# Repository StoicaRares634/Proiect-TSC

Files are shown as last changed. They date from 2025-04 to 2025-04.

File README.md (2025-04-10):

# Proiect-TSC
Proiect-TSC Stoica Rares-Nicolae 333CA

| Device | CHECK_PRICES |
|---|---|
| ESP32_WROVER_EAGLE-LTSPICE_CC0402 | |
| RCL_CPOL-EUCT3528 | https://a360.co/4iZy6AA |
| CPH3225A | https://www.snapeda.com/parts/CPH3225A/Seiko+Instruments/view-part/?ref=eda |
| BUTTON_CUSYOMV1 | https://industry.panasonic.com/global/en/products/control/switch/light-touch/number/evqpuj02k |
| ADAFRUIT_LEDCHIP-LED0603 | https://www.snapeda.com/parts/KP-1608SURCK/Kingbright/view-part/?ref=search |
| USBLC6-2SC6Y | https://www.snapeda.com/parts/USBLC6-2SC6Y/STMicroelectronics/view-part/?ref=eda |
| ESP32_WROVER_AVX---SD0805S020S1R0 | https://eu.mouser.com/ProductDetail/KYOCERA-AVX/SD0805S020S1R0?qs=jCA%252BPfw4LHbpkAoSnwrdjw%3D%3D |
| MBR0530 | https://www.snapeda.com/parts/MBR0530/Onsemi/view-part/?ref=eda |
| PGB1010603MR | https://www.snapeda.com/parts/PGB1010603MR/Littelfuse/view-part/?ref=eda |
| BD5229G-TR | https://componentsearchengine.com/part-view/BD5229G-TR/ROHM%20Semiconductor |
| XC6220A331MR-G | https://componentsearchengine.com/part-view/XC6220A331MR-G/Torex |
| FH34SRJ-24S-0.5SH_99_ | https://componentsearchengine.com/part-view/XC6220A331MR-G/Torex |
| SAMACSYS_PARTS_USB4110-GF-A | https://componentsearchengine.com/part-view/USB4110-GF-A/GCT%20(GLOBAL%20CONNECTOR%20TECHNOLOGY) |
| 112A-TAAR-R03_ATTEND | https://store.comet.srl.ro/Catalogue/Product/43497/ |
| 744043680IND_4828-WE-TPC_WRE | https://eu.mouser.com/ProductDetail/Wurth-Elektronik/744043680?qs=PGXP4M47uW6VkZq%252BkzjrHA%3D%3D |
| ESP32C6_VARISTORCN1812 | https://www.mouser.co.uk/ProductDetail/EPCOS-TDK/B72520T0350K062?qs=dEfas%2FXlABIszF52uu7vrg%3D%3D |
| ESP32_WROVER_SPARKFUN-DISCRETESEMI_MOSFET_PCH-DMG2305UX-7 | https://componentsearchengine.com/part-view/DMG2305UX-7/Diodes%20Incorporated |
| D8 | https://componentsearchengine.com/part-view/SI1308EDL-T1-GE3/Vishay |
| ESP32_WROVER_EAGLE-LTSPICE_RR0402 | https://componentsearchengine.com/part-view/R0402%201%25%20100%20K%20(RC0402FR-07100KL)/YAGEO |
| BME680 | https://www.snapeda.com/parts/BME680/Bosch/view-part/?welcome=home |
| SJ | https://grabcad.com/library/solder-jumpers-1 |
| W25Q512JVEIQ | https://www.snapeda.com/parts/W25Q512JVEIQ/Winbond+Electronics/view-part/?ref=eda |
| ESP32-C6-WROOM-1-N8 | https://www.snapeda.com/parts/ESP32-C6-WROOM-1-N8/Espressif+Systems/view-part/?ref=eda |
| DS3231SN# | https://www.snapeda.com/parts/DS3231SN%23/Analog+Devices/view-part/?ref=eda |
| MAX17048G+T10 | https://www.snapeda.com/parts/MAX17048G+T10/Analog+Devices/view-part/?ref=eda |

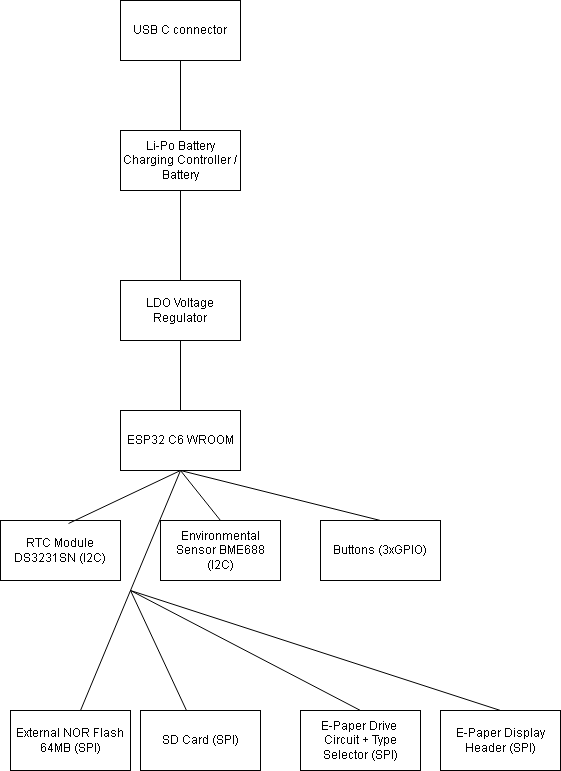
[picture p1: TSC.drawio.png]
diagrama


## Descriere detaliata a functionalitatii hardware

Proiectul utilizeaza microcontroller-ul ESP32-C6 WROOM. Acesta gestioneaza comunicatia cu diverse module prin interfete SPI, I2C si GPIO, avand capacitate extinsa pentru conectivitate wireless si control de periferice.

### Structura de alimentare

- Conector USB-C: asigura alimentarea externa si transferul de date.
- Controler incarcare baterie Li-Po (MCP73831): integreaza functii de incarcare sigura si controlata a bateriei.
- Baterie Li-Po: sursa de energie mobila, folosita pentru autonomie.
- LDO Regulator (XC6206): reduce tensiunea de la baterie la 3.3V stabili, necesari ESP32 si altor componente.

### Module conectate la ESP32-C6 si interfetele lor

#### 1. Senzor ambiental BME688
- Interfata: I2C
- Functii: detecteaza temperatura, presiune, umiditate si compusi volatili (calitate aer).
- Pini ESP32-C6:
  - GPIO4 → SDA
  - GPIO5 → SCL
GPIO4 si GPIO5 sunt GPIO standard cu suport I2C hardware.

#### 2. Modul RTC – DS3231SN
- Interfata: I2C
- Functii: mentine timpul real precis, inclusiv in standby.
- Pini ESP32-C6:
  - Impartiti cu BME688: GPIO4 (SDA) si GPIO5 (SCL)

#### 3. Memorie externa NOR Flash – W25Q512JVEIQ
- Interfata: SPI
- Functii: stocare extensiva de date nevolatile (64MB).
- Pini ESP32-C6:
  - GPIO6 → CLK
  - GPIO7 → MISO
  - GPIO8 → MOSI
  - GPIO9 → CS (Flash)
Aceasta configuratie este conforma cu pinii dedicati SPI al ESP32-C6 pentru performanta maxima.

#### 4. Modul SD Card
- Interfata: SPI (partajata cu NOR Flash)
- Pini ESP32-C6:
  - GPIO10 → CS (SD Card)
Se foloseste acelasi bus SPI ca Flash-ul, dar cu CS separat pentru selectare.

#### 5. E-Paper Display
- Subcomponente:
  - Circuit de tip e-paper + selector de tip ecran
  - Header pentru display
- Interfata: SPI
- Pini ESP32-C6:
  - GPIO11 → CS (E-Paper)
  - GPIO12 → RES (Reset)
  - GPIO13 → BUSY (Stare de incarcare)
GPIO11–13 sunt configurabili si sunt utilizati pentru semnale de control specifice E-Paper.

#### 6. Butoane de control (BOOT, RESET, CHANGE)
- Interfata: GPIO
- Pini ESP32-C6:
  - GPIO0 → BOOT
  - GPIO1 → RESET
  - GPIO2 → CHANGE
- Utilitate: ofera control manual pentru operatii precum boot, test sau configurare.

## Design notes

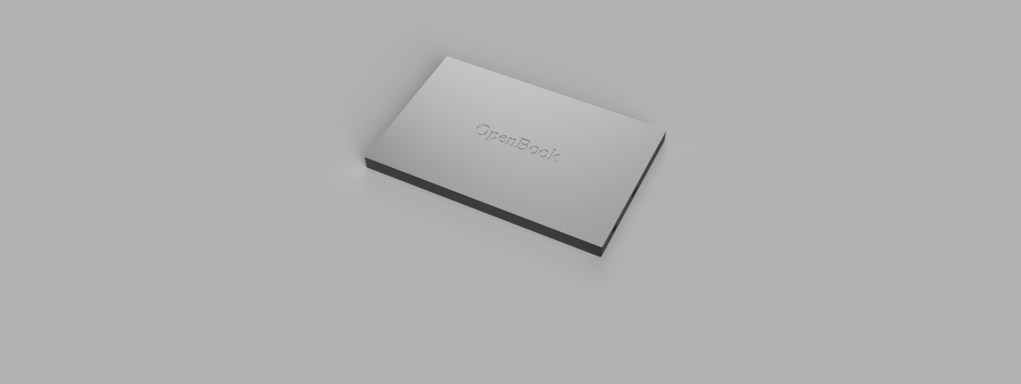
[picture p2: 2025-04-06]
Images/open_book.png

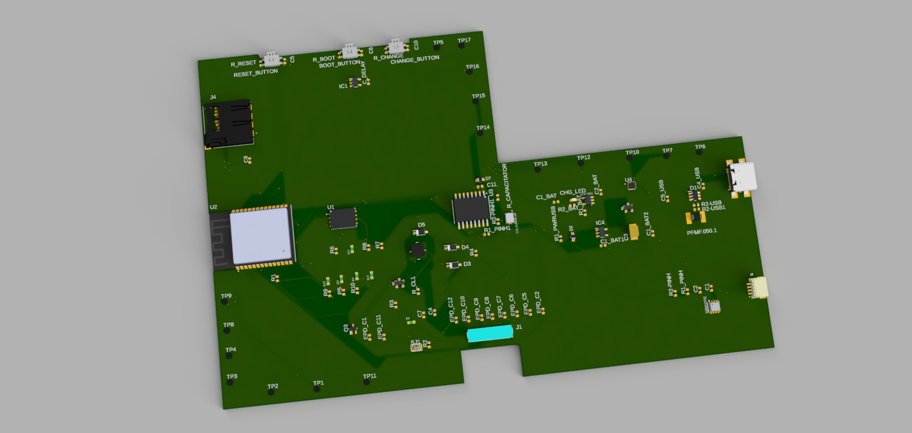
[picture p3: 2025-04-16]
Images/pcb.png

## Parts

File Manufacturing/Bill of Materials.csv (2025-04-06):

Qty | Value | Device | Package | Parts | Description | ARROW_PART_NUMBER | ARROW_PRICE-STOCK | AVAILABILITY | CENTROID_NOT_SPECIFIED | CHECK_PRICES | COPYRIGHT | DATASHEET | DESCRIPTION | DIGIKEY_DESCRIPTION | DIGIKEY_PART_NUMBER | HEIGHT | LEAD_FREE | MANUFACTURER_NAME | MANUFACTURER_PART_NUMBER | MF | MFR_NAME | MOUSER_PART_NUMBER | MOUSER_PRICE-STOCK | MOUSER_TESTING_PART_NUMBER | MOUSER_TESTING_PRICE-STOCK | MP | MPN | PACKAGE | POPULARITY | PREFIX | PRICE | PROD_ID | PURCHASE-URL | ROHS | SNAPEDA_LINK | SPICEMODEL | SPICEPREFIX | TEMPERATURE_RANGE_HIGH | TEMPERATURE_RANGE_LOW | TP_SIGNAL_NAME | VALUE
1 |  | ADAFRUIT_LEDCHIP-LED0603 | ADAFRUIT_CHIP-LED0603 | CHG_LED | LED
1 |  | SJ | SJ | SJ1 | SMD solder JUMPER |  |  |  |  |  |  |  |  |  |  |  |  |  |  |  |  |  |  |  |  |  |  |  | 3
1 | 0.47 | ESP32_WROVER_EAGLE-LTSPICE_RR0402 | ESP32_WROVER_EAGLE-LTSPICE_R0402 | R3 | RESISTOR, European symbol |  |  |  |  |  |  |  |  |  |  |  |  |  |  |  |  |  |  |  |  |  |  |  |  |  |  |  |  |  |  | NONE | R
1 | 100K | ESP32_WROVER_EAGLE-LTSPICE_RR0402 | ESP32_WROVER_EAGLE-LTSPICE_R0402 | R1_PWRUSB | RESISTOR, European symbol |  |  |  |  |  |  |  |  |  |  |  |  |  |  |  |  |  |  |  |  |  |  |  |  |  |  |  |  |  |  | NONE | R
6 | 100nF | EAGLE-LTSPICE_CC0402 | EAGLE-LTSPICE_C0402 | C1, C2, C4_USB, C6, C10, C_DELAY | CAPACITOR, European symbol |  |  |  |  |  |  |  |  |  |  |  |  |  |  |  |  |  |  |  |  |  |  |  |  |  |  |  |  |  |  | NONE | C
2 | 100nF | ESP32_WROVER_EAGLE-LTSPICE_CC0402 | ESP32_WROVER_EAGLE-LTSPICE_C0402 | C9, C11 | CAPACITOR, European symbol |  |  |  |  |  |  |  |  |  |  |  |  |  |  |  |  |  |  |  |  |  |  |  |  |  |  |  |  |  |  | NONE | C
1 | 100uF TANT | RCL_CPOL-EUCT3528 | RCL_CT3528 | C3 | POLARIZED CAPACITOR, European symbol |  |  |  |  |  |  |  |  |  |  |  |  |  |  |  |  |  |  |  |  |  |  |  | 0 |  |  |  |  |  |  |  | C
16 | 10K | ESP32_WROVER_EAGLE-LTSPICE_RR0402 | ESP32_WROVER_EAGLE-LTSPICE_R0402 | R1, R1_PINH, R1_PINH1, R2-PINH, R2-PINH1, R4, R5, R6, R7, R8, R9, R10, R_BOOT, R_CHANGE, R_CL1, R_RESET | RESISTOR, European symbol |  |  |  |  |  |  |  |  |  |  |  |  |  |  |  |  |  |  |  |  |  |  |  |  |  |  |  |  |  |  | NONE | R
1 | 10uF | EAGLE-LTSPICE_CC0402 | EAGLE-LTSPICE_C0402 | C7 | CAPACITOR, European symbol |  |  |  |  |  |  |  |  |  |  |  |  |  |  |  |  |  |  |  |  |  |  |  |  |  |  |  |  |  |  | NONE | C
1 | 112A-TAAR-R03_ATTEND | 112A-TAAR-R03_ATTEND | 112ATAARR03ATTEND | J4 | Micro SD Card Socket, Push-Push Type, Top Mount, SMT, H=1.83mm, 10u |  |  |  |  |  |  |  | Micro SD Card Socket | Push-Push Type | Top Mount | SMT | H=1.83mm | 10u |  |  | 1.9mm |  | ATTEND | 112A-TAAR-R03 ATTEND
1 | 15 | ESP32_WROVER_EAGLE-LTSPICE_RR0402 | ESP32_WROVER_EAGLE-LTSPICE_R0402 | R_CAPACITATOR | RESISTOR, European symbol |  |  |  |  |  |  |  |  |  |  |  |  |  |  |  |  |  |  |  |  |  |  |  |  |  |  |  |  |  |  | NONE | R
1 | 1uF | EAGLE-LTSPICE_CC0402 | EAGLE-LTSPICE_C0402 | C5 | CAPACITOR, European symbol |  |  |  |  |  |  |  |  |  |  |  |  |  |  |  |  |  |  |  |  |  |  |  |  |  |  |  |  |  |  | NONE | C
10 | 1uF/50V | EAGLE-LTSPICE_CC0402 | EAGLE-LTSPICE_C0402 | EPD_C1, EPD_C2, EPD_C5, EPD_C6, EPD_C7, EPD_C8, EPD_C9, EPD_C10, EPD_C11, EPD_C12 | CAPACITOR, European symbol |  |  |  |  |  |  |  |  |  |  |  |  |  |  |  |  |  |  |  |  |  |  |  |  |  |  |  |  |  |  | NONE | C
1 | 2.2 | ESP32_WROVER_EAGLE-LTSPICE_RR0402 | ESP32_WROVER_EAGLE-LTSPICE_R0402 | R2 | RESISTOR, European symbol |  |  |  |  |  |  |  |  |  |  |  |  |  |  |  |  |  |  |  |  |  |  |  |  |  |  |  |  |  |  | NONE | R
1 | 200 | ESP32_WROVER_EAGLE-LTSPICE_RR0402 | ESP32_WROVER_EAGLE-LTSPICE_R0402 | R1_BAT | RESISTOR, European symbol |  |  |  |  |  |  |  |  |  |  |  |  |  |  |  |  |  |  |  |  |  |  |  |  |  |  |  |  |  |  | NONE | R
2 | 20V/4.2A/52mO/1.4W | ESP32_WROVER_SPARKFUN-DISCRETESEMI_MOSFET_PCH-DMG2305UX-7 | ESP32_WROVER_SPARKFUN-DISCRETESEMI_SOT23-3 | Q1, Q2 | P-channel MOSFETs |  |  |  |  |  |  |  |  |  |  |  |  |  |  |  |  |  |  |  |  |  |  |  |  |  |  | TRAN-14388 |  |  |  |  |  |  |  |  | 20V/4.2A/52mO/1.4W
1 | 2K | ESP32_WROVER_EAGLE-LTSPICE_RR0402 | ESP32_WROVER_EAGLE-LTSPICE_R0402 | R2_BAT | RESISTOR, European symbol |  |  |  |  |  |  |  |  |  |  |  |  |  |  |  |  |  |  |  |  |  |  |  |  |  |  |  |  |  |  | NONE | R
3 | 4.7uF | EAGLE-LTSPICE_CC0402 | EAGLE-LTSPICE_C0402 | C1_BAT, C1_BAT1, C5_USB | CAPACITOR, European symbol |  |  |  |  |  |  |  |  |  |  |  |  |  |  |  |  |  |  |  |  |  |  |  |  |  |  |  |  |  |  | NONE | C
2 | 4.7uF | ESP32_WROVER_EAGLE-LTSPICE_CC0402 | ESP32_WROVER_EAGLE-LTSPICE_C0402 | C1_BAT2, C2_BAT | CAPACITOR, European symbol |  |  |  |  |  |  |  |  |  |  |  |  |  |  |  |  |  |  |  |  |  |  |  |  |  |  |  |  |  |  | NONE | C
1 | 4.7uF/25V | ESP32_WROVER_EAGLE-LTSPICE_CC0402 | ESP32_WROVER_EAGLE-LTSPICE_C0402 | C4 | CAPACITOR, European symbol |  |  |  |  |  |  |  |  |  |  |  |  |  |  |  |  |  |  |  |  |  |  |  |  |  |  |  |  |  |  | NONE | C
2 | 5k1 | ESP32_WROVER_EAGLE-LTSPICE_RR0402 | ESP32_WROVER_EAGLE-LTSPICE_R0402 | R2-USB, R2-USB1 | RESISTOR, European symbol |  |  |  |  |  |  |  |  |  |  |  |  |  |  |  |  |  |  |  |  |  |  |  |  |  |  |  |  |  |  | NONE | R
1 | 68uH | 744043680IND_4828-WE-TPC_WRE | IND_4828-WE-TPC_WRE | L1 |  |  |  |  |  |  | Copyright (C) 2024 Ultra Librarian. All rights reserved. |  |  |  |  |  |  |  | 744043680 |  | Wurth Electronics
1 | BD5229G-TR | BD5229G-TR | SOT95P280X125-5N | IC1 | Voltage Detector with Adjustable Delay Time: CMOS processes are utilized to develop high precision, low current consumption CMOS reset ICs that allow arbitrary setting of the delay time. The extensive lineup includes both Nch Open Drain and CMOS output types in a wide range of detection voltages (from 2.3V to 6.0V, in 0.1V steps), enabling selection of the ideal solution based on customer requirements. In addition, the entire series is of course both lead-free and RoHS-compliant. |  |  |  |  |  |  |  | Voltage Detector with Adjustable Delay Time: CMOS processes are utilized to develop high precision | low current consumption CMOS reset ICs that allow arbitrary setting of the delay time. The extensive lineup includes both Nch Open Drain and CMOS output types in a wide range of detection voltages (from 2.3V to 6.0V | in 0.1V steps) | enabling selection of the ideal solution based on customer requirements. In addition | the entire series is of course both lead-free and RoHS-compliant. |  |  | 1.25mm |  | ROHM Semiconductor | BD5229G-TR |  |  | 755-BD5229G-TR | https://www.mouser.co.uk/ProductDetail/ROHM-Semiconductor/BD5229G-TR?qs=4kLU8WoGk0vvnhrrYwdszw%3D%3D
3 | BUTTON_CUSYOMV1 | BUTTON_CUSYOMV1 | MYBUTTON | BOOT_BUTTON, CHANGE_BUTTON, RESET_BUTTON
1 | CPH3225A | CPH3225A | CAPCP3225X100N | C10_SUPERCAP | Cap 0.011F 3.3V 1210 Flat Check availability |  |  | Not in stock |  | https://www.snapeda.com/parts/CPH3225A/Seiko+Instruments/view-part/?ref=eda |  |  | 11 mF (EDLC) Supercapacitor 3.3 V 1210 (3225 Metric) - - |  |  |  |  |  |  | Seiko Instruments |  |  |  |  |  | CPH3225A |  | 1210 Seiko |  |  | None |  | https://www.snapeda.com/api/url_track_click_mouser/?unipart_id=562593&manufacturer=Seiko Instruments&part_name=CPH3225A&search_term=None |  | https://www.snapeda.com/parts/CPH3225A/Seiko+Instruments/view-part/?ref=snap
1 | DS3231SN# | DS3231SN# | SOIC127P1032X265-16N | U3 | Real Time Clock Serial 16-Pin SOIC W T/R Check availability |  |  | In Stock |  | https://www.snapeda.com/parts/DS3231SN%23/Analog+Devices/view-part/?ref=eda |  |  | Extremely Accurate I²C-Integrated RTC/TCXO/Crystal |  |  |  |  |  |  | Analog Devices |  |  |  |  |  | DS3231SN# |  | SOIC-16 Maxim |  |  | None |  | https://www.snapeda.com/api/url_track_click_mouser/?unipart_id=99048&manufacturer=Analog Devices&part_name=DS3231SN#&search_term=None |  | https://www.snapeda.com/parts/DS3231SN%23/Analog+Devices/view-part/?ref=snap
1 | ESP32-C6-WROOM-1-N8 | ESP32-C6-WROOM-1-N8 | XCVR_ESP32-C6-WROOM-1-N8 | U2 | Check availability |  |  | In Stock |  | https://www.snapeda.com/parts/ESP32-C6-WROOM-1-N8/Espressif+Systems/view-part/?ref=eda |  |  | Multiprotocol Modules ESP32-C6 module | Wi-Fi 6 in 2.4 GHz band | Bluetooth 5 | Zigbee 3.0 and Thread. ESP34-WROOM Compatible - ENGINEERING SAMPLE |  |  |  |  |  |  | Espressif Systems |  |  |  |  |  | ESP32-C6-WROOM-1-N8 |  | None |  |  | None |  |  |  | https://www.snapeda.com/parts/ESP32-C6-WROOM-1-N8/Espressif+Systems/view-part/?ref=snap
1 | ESP32C6_VARISTORCN1812 | ESP32C6_VARISTORCN1812 | ESP32C6_VARISTOR_CT/CN1812 | PFMF.050.1 | VARISTOR |  |  |  |  |  |  |  |  |  |  |  |  |  |  |  |  |  |  |  |  |  |  |  | 0
2 | ESP32_WROVER_AVX---SD0805S020S1R0_AVX_SD0805S020S1R0_0_0AVX_SD0805S020S1R0_0_0 | ESP32_WROVER_AVX---SD0805S020S1R0_AVX_SD0805S020S1R0_0_0AVX_SD0805S020S1R0_0_0 | ESP32_WROVER_AVX---SD0805S020S1R0_AVX_SD0805S020S1R0_0 | D2, D7 | Schottky Barrier Rectifier Diode |  |  |  | No |  |  | http://datasheets.avx.com/schottky.pdf |  | DIODE SCHOTTKY 20V 1A 0805 | 478-7800-1-ND |  | yes |  |  | AVX |  | 581-SD0805S020S1R0 |  |  |  |  |  | 0805 (2012 metric) |  | D |  |  |  | yes |  |  |  | +125°C | -55°C
1 | ESP32_WROVER_BME680_BME680 | ESP32_WROVER_BME680_BME680 | ESP32_WROVER_BME680_PSON80P300X300X100-8N | SENSOR2 | Integrated Environmental Unit |  |  | Unavailable |  |  |  |  | Integrated Environmental Unit |  |  |  |  |  |  | Bosch Sensortec |  |  |  |  |  | BME680 |  | LGA-8 Bosch Tools |  |  | None
1 | ESP32_WROVER_SPARKFUN-IC-POWER_MCP73831 | ESP32_WROVER_SPARKFUN-IC-POWER_MCP73831 | ESP32_WROVER_SPARKFUN-IC-POWER_SOT23-5 | MCP73831 | MCP73831T Li-Ion, Li-Pol Controller |  |  |  |  |  |  |  |  |  |  |  |  |  |  |  |  |  |  |  |  |  |  |  |  |  |  | IC-09995
1 | FH34SRJ-24S-0.5SH_99_ | FH34SRJ-24S-0.5SH_99_ | FH34SRJ24S05SH99 | J1 | (0.50mm) Surface Mount, Right Angle |  |  |  |  |  |  |  | 24 Position FFC | FPC Connector Contacts | (0.50mm) Surface Mount | Right Angle |  |  | 1.1mm |  | Hirose | FH34SRJ-24S-0.5SH(99) |  |  | 798-FH34SRJ24S05SH99 | https://www.mouser.co.uk/ProductDetail/Hirose-Connector/FH34SRJ-24S-0.5SH99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
1 | MAX17048G+T10 | MAX17048G+T10 | SON50P200X200X80-9N | U4 | Check availability |  |  | In Stock |  | https://www.snapeda.com/parts/MAX17048G+T10/Analog+Devices/view-part/?ref=eda |  |  | 3µA 1-Cell/2-Cell Fuel Gauge with ModelGauge |  |  |  |  |  |  | Analog Devices |  |  |  |  |  | MAX17048G+T10 |  | TDFN-8 Maxim |  |  | None |  | https://www.snapeda.com/api/url_track_click_mouser/?unipart_id=329239&manufacturer=Analog Devices&part_name=MAX17048G+T10&search_term=None |  | https://www.snapeda.com/parts/MAX17048G+T10/Analog+Devices/view-part/?ref=snap
3 | MBR0530 | MBR0530 | SOD3716X135N | D3, D4, D5 | ON SEMICONDUCTOR - MBR0530 - DIODE, SCHOTTKY, 0.5A, 30V, SOD-123 |  |  | In Stock |  | https://www.snapeda.com/parts/MBR0530/Onsemi/view-part/?ref=eda |  |  | Diode Schottky 30 V 500mA Surface Mount SOD-123 |  |  |  |  |  |  | ON Semiconductor |  |  |  |  |  | MBR0530 |  | SOD-123-2 ON Semiconductor |  |  | None |  | https://www.snapeda.com/api/url_track_click_mouser/?unipart_id=179458&manufacturer=ON Semiconductor&part_name=MBR0530&search_term=None |  | https://www.snapeda.com/parts/MBR0530/Onsemi/view-part/?ref=snap
6 | PGB1010603MR | PGB1010603MR | DIOC1608X36N | D6, D8, D9, D10, D11, D12 | Check availability |  |  | In Stock |  | https://www.snapeda.com/parts/PGB1010603MR/Littelfuse/view-part/?ref=eda |  |  | 150V (Typ) Clamp - Ipp Tvs Diode Surface Mount 0603 (1608 Metric) |  |  |  |  |  |  | Littelfuse Inc. |  |  |  |  |  | PGB1010603MR |  | 0603 Littelfuse Inc. |  |  | None |  | https://www.snapeda.com/api/url_track_click_mouser/?unipart_id=5659453&manufacturer=Littelfuse Inc.&part_name=PGB1010603MR&search_term=None |  | https://www.snapeda.com/parts/PGB1010603MR/Littelfuse/view-part/?ref=snap
1 | QWIIC_RIGHT_ANGLE | QWIIC_CONNECTORJS-1MM | JST04_1MM_RA | J3 | SparkFun I2C Standard Qwiic Connector |  |  |  |  |  |  |  |  |  |  |  |  |  |  |  |  |  |  |  |  |  |  |  |  |  |  | CONN-13694 |  |  |  |  |  |  |  |  | QWIIC_RIGHT_ANGLE
1 | SAMACSYS_PARTS_USB4110-GF-A | SAMACSYS_PARTS_USB4110-GF-A | SAMACSYS_PARTS_USB4110GFA | J2 | CONN USB 2.0 TYPE-C R/A SMT |  |  |  |  |  |  |  | CONN USB 2.0 TYPE-C R/A SMT |  |  | 3.26mm |  | GCT (GLOBAL CONNECTOR TECHNOLOGY) | USB4110-GF-A |  |  | 640-USB4110-GF-A | https://www.mouser.co.uk/ProductDetail/GCT/USB4110-GF-A?qs=KUoIvG%2F9IlYiZvIXQjyJeA%3D%3D
1 | SI1308EDL-T1-GE3 | SI1308EDL-T1-GE3 | SOT65P210X110-3N | Q3 | MOSFET N-Ch 30V 1.5A TrenchFET SC70 Vishay Si1308EDL-T1-GE3 N-channel MOSFET Transistor, 1.5 A, 30 V, 3-Pin SC-70 |  |  | In Stock |  | https://www.snapeda.com/parts/SI1308EDL-T1-GE3/Vishay+Siliconix/view-part/?ref=eda |  |  | Si1308EDL-T1-GE3 N-channel MOSFET Transistor | 1.5 A | 30 V | 3-Pin SC-70 | Siliconix / Vishay SI1308EDL-T1-GE3 |  |  |  |  |  |  | Vishay Siliconix |  |  |  |  |  | SI1308EDL-T1-GE3 |  | SOT-323 Vishay Semiconductor |  |  | None |  | https://www.snapeda.com/api/url_track_click_mouser/?unipart_id=274603&manufacturer=Vishay Siliconix&part_name=SI1308EDL-T1-GE3&search_term=None |  | https://www.snapeda.com/parts/SI1308EDL-T1-GE3/Vishay+Siliconix/view-part/?ref=snap
17 | TPTP20R | TPTP20R | TP20R | TP1, TP2, TP3, TP4, TP5, TP6, TP7, TP8, TP9, TP10, TP11, TP12, TP13, TP14, TP15, TP16, TP17 | Test pad |  |  |  |  |  |  |  |  |  |  |  |  |  |  |  |  |  |  |  |  |  |  |  | 2
1 | USBLC6-2SC6Y | USBLC6-2SC6Y | SOT95P280X145-6N | D1 | Low Cap. ESD Protection Auto SOT-23-6 STMicroelectronics USBLC6-2SC6Y, Dual Uni-Directional TVS Diode Array, 6-Pin SOT-23 |  |  | In Stock |  | https://www.snapeda.com/parts/USBLC6-2SC6Y/STMicroelectronics/view-part/?ref=eda |  |  | 17V Clamp 5A (8/20µs) Ipp Tvs Diode Surface Mount SOT-23-6 |  |  |  |  |  |  | STMicroelectronics |  |  |  |  |  | USBLC6-2SC6Y |  | SOT-23-6 STMicroelectronics |  |  | None |  |  |  | https://www.snapeda.com/parts/USBLC6-2SC6Y/STMicroelectronics/view-part/?ref=snap
1 | W25Q512JVEIQ | W25Q512JVEIQ | SON127P600X800X80-9N | U1 | Check availability |  |  | In Stock |  | https://www.snapeda.com/parts/W25Q512JVEIQ/Winbond+Electronics/view-part/?ref=eda |  |  | FLASH - NOR Memory IC 512Mb (64M x 8) SPI - Quad I/O 133 MHz 8-WSON (8x6) |  |  |  |  |  |  | Winbond Electronics |  |  |  |  |  | W25Q512JVEIQ |  | Package |  |  | None |  |  |  | https://www.snapeda.com/parts/W25Q512JVEIQ/Winbond+Electronics/view-part/?ref=snap
1 | XC6220A331MR-G | XC6220A331MR-G | SOT95P280X120-5N | IC4 | LDO Voltage Regulators |  |  |  |  |  |  |  | LDO Voltage Regulators |  |  | 1.2mm |  | Torex | XC6220A331MR-G |  |  | 865-XC6220A331MR-G | https://www.mouser.co.uk/ProductDetail/Torex-Semiconductor/XC6220A331MR-G?qs=AsjdqWjXhJ8ZSWznL1J0gg%3D%3D

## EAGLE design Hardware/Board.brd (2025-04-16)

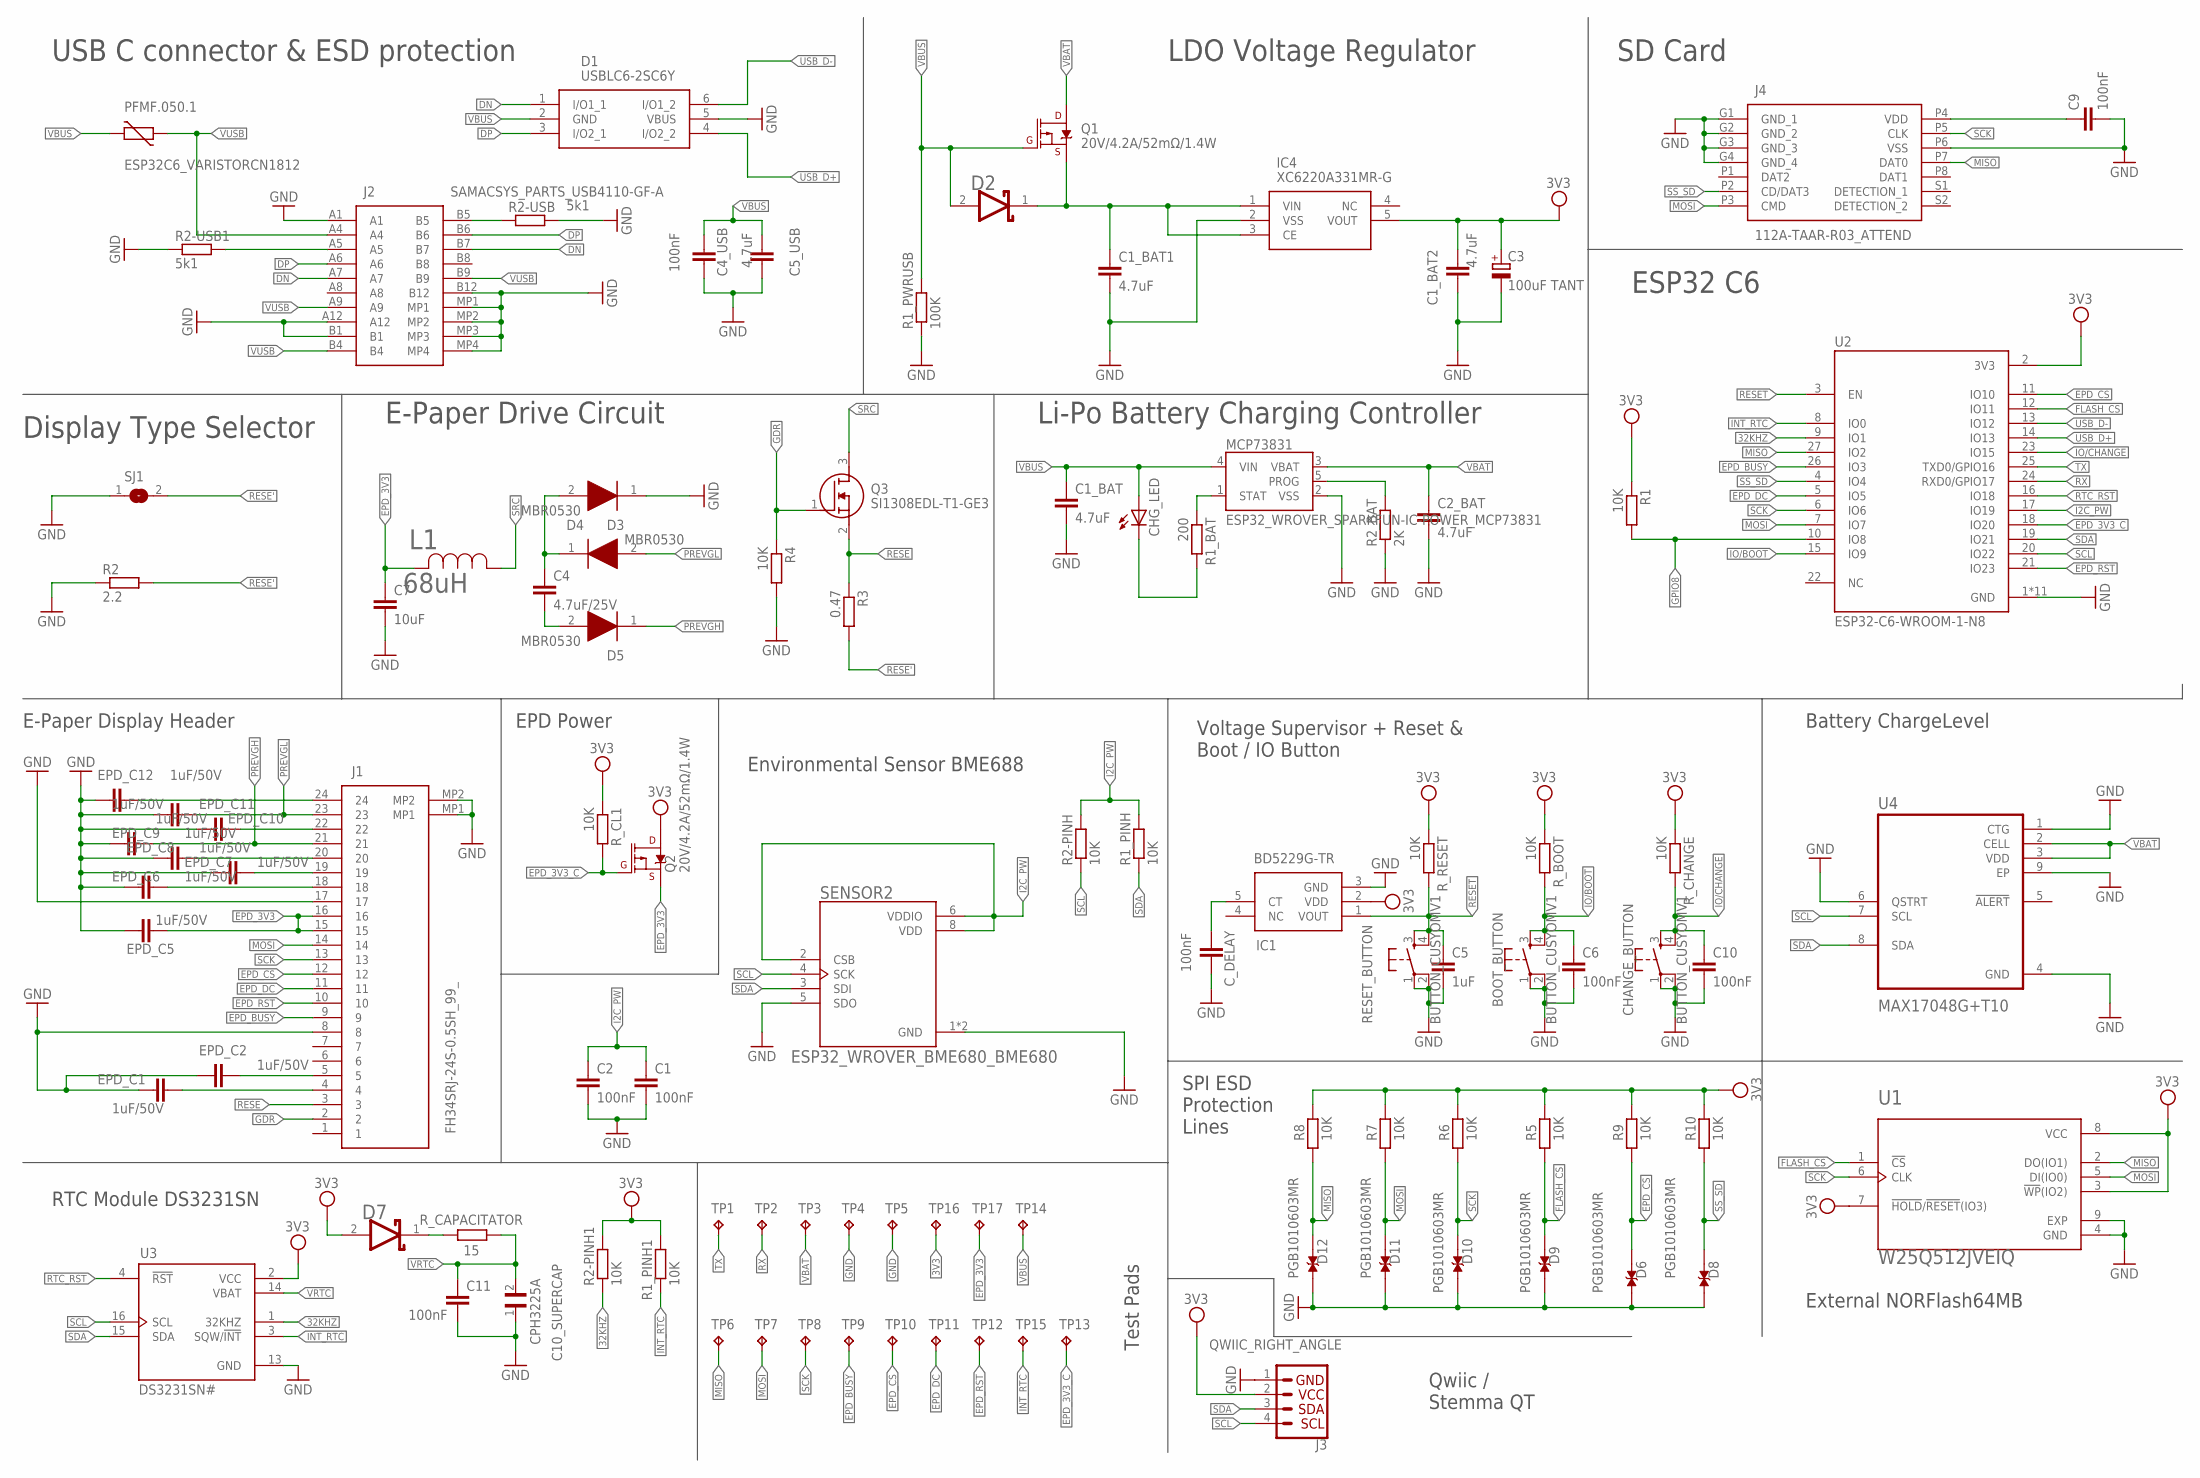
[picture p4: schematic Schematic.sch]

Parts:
BOOT_BUTTON: BUTTON_CUSYOMV1; MYBUTTON
C1, C2, C4_USB, C6, C10: 100nF; EAGLE-LTSPICE_C0402
C1_BAT, C1_BAT1, C5_USB: 4.7uF; EAGLE-LTSPICE_C0402
C1_BAT2, C2_BAT: 4.7uF; ESP32_WROVER_EAGLE-LTSPICE_C0402
C3: 100uF TANT; RCL_CT3528
C4: 4.7uF/25V; ESP32_WROVER_EAGLE-LTSPICE_C0402
C5: 1uF; EAGLE-LTSPICE_C0402
C7: 10uF; EAGLE-LTSPICE_C0402
C9, C11: 100nF; ESP32_WROVER_EAGLE-LTSPICE_C0402
C10_SUPERCAP: CPH3225A; CAPCP3225X100N
CHANGE_BUTTON: BUTTON_CUSYOMV1; MYBUTTON
CHG_LED: ADAFRUIT_LEDCHIP-LED0603; ADAFRUIT_CHIP-LED0603
C_DELAY: 100nF; EAGLE-LTSPICE_C0402
D1: USBLC6-2SC6Y; SOT95P280X145-6N
D2, D7: ESP32_WROVER_AVX---SD0805S020S1R0_AVX_SD0805S020S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; ESP32_WROVER_AVX---SD0805S020S1R0_AVX_SD0805S020S1R0_0
D3, D4, D5: MBR0530; SOD3716X135N
D6, D8, D9, D10, D11, D12: PGB1010603MR; DIOC1608X36N
EPD_C1, EPD_C2, EPD_C5, EPD_C6, EPD_C7, EPD_C8, EPD_C9, EPD_C10, EPD_C11, EPD_C12: 1uF/50V; EAGLE-LTSPICE_C0402
IC1: BD5229G-TR; SOT95P280X125-5N
IC4: XC6220A331MR-G; SOT95P280X120-5N
J1: FH34SRJ-24S-0.5SH_99_; FH34SRJ24S05SH99
J2: SAMACSYS_PARTS_USB4110-GF-A; SAMACSYS_PARTS_USB4110GFA
J3: QWIIC_RIGHT_ANGLE; JST04_1MM_RA
J4: 112A-TAAR-R03_ATTEND; 112ATAARR03ATTEND
L1: 68uH; IND_4828-WE-TPC_WRE
MCP73831: ESP32_WROVER_SPARKFUN-IC-POWER_MCP73831; ESP32_WROVER_SPARKFUN-IC-POWER_SOT23-5
PFMF.050.1: ESP32C6_VARISTORCN1812; ESP32C6_VARISTOR_CT/CN1812
Q1, Q2: 20V/4.2A/52mΩ/1.4W; ESP32_WROVER_SPARKFUN-DISCRETESEMI_SOT23-3
Q3: SI1308EDL-T1-GE3; SOT65P210X110-3N
R1, R1_PINH, R1_PINH1, R2-PINH, R2-PINH1, R4, R5, R6, R7, R8, R9, R10: 10K; ESP32_WROVER_EAGLE-LTSPICE_R0402
R1_BAT: 200; ESP32_WROVER_EAGLE-LTSPICE_R0402
R1_PWRUSB: 100K; ESP32_WROVER_EAGLE-LTSPICE_R0402
R2: 2.2; ESP32_WROVER_EAGLE-LTSPICE_R0402
R2-USB, R2-USB1: 5k1; ESP32_WROVER_EAGLE-LTSPICE_R0402
R2_BAT: 2K; ESP32_WROVER_EAGLE-LTSPICE_R0402
R3: 0.47; ESP32_WROVER_EAGLE-LTSPICE_R0402
RESET_BUTTON: BUTTON_CUSYOMV1; MYBUTTON
R_BOOT: 10K; ESP32_WROVER_EAGLE-LTSPICE_R0402
R_CAPACITATOR: 15; ESP32_WROVER_EAGLE-LTSPICE_R0402
R_CHANGE: 10K; ESP32_WROVER_EAGLE-LTSPICE_R0402
R_CL1: 10K; ESP32_WROVER_EAGLE-LTSPICE_R0402
R_RESET: 10K; ESP32_WROVER_EAGLE-LTSPICE_R0402
SENSOR2: ESP32_WROVER_BME680_BME680; ESP32_WROVER_BME680_PSON80P300X300X100-8N
SJ1: SJ
TP1, TP2, TP3, TP4, TP5, TP6, TP7, TP8, TP9, TP10, TP11, TP12, TP13, TP14, TP15, TP16, TP17: TPTP20R; TP20R
U1: W25Q512JVEIQ; SON127P600X800X80-9N
U2: ESP32-C6-WROOM-1-N8; XCVR_ESP32-C6-WROOM-1-N8
U3: DS3231SN#; SOIC127P1032X265-16N
U4: MAX17048G+T10; SON50P200X200X80-9N

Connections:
3V3: C1_BAT2.1, C3.+, D7.2 (ANODE), IC1.2 (VDD), IC4.5 (VOUT), J3.2, Q2.3 (D), R1.1, R1_PINH1.2, R2-PINH1.2, R5.2, R6.2, R7.2, R8.2, R9.2, R10.2, R_BOOT.1, R_CHANGE.1, R_CL1.1, R_RESET.1, TP16.TP, U1.3 (!WP!(IO2)), U1.7 (!HOLD!/!RESET!(IO3)), U1.8 (VCC), U2.2 (3V3), U3.2 (VCC)
32KHZ: R2-PINH1.1, U2.9 (IO1), U3.1 (32KHZ)
DN: D1.1 (I/O1_1), J2.A7, J2.B7
DP: D1.3 (I/O2_1), J2.A6, J2.B6
EPD_3V3: C7.1, EPD_C5.1, J1.15, J1.16, L1.2, Q2.2 (S), TP17.TP
EPD_3V3_C: Q2.1 (G), R_CL1.2, TP13.TP, U2.18 (IO20)
EPD_BUSY: J1.9, TP9.TP, U2.26 (IO3)
EPD_CS: D6.2, J1.12, R9.1, TP10.TP, U2.11 (IO10)
EPD_DC: J1.11, TP11.TP, U2.5 (IO5)
EPD_RST: J1.10, TP12.TP, U2.21 (IO23)
FLASH_CS: D9.2, R5.1, U1.1 (!CS), U2.12 (IO11)
GDR: J1.2, Q3.1 (G), R4.1
GND: BOOT_BUTTON.1, BOOT_BUTTON.2, C1.2, C1_BAT.2, C1_BAT1.2, C1_BAT2.2, C2.2, C2_BAT.2, C3.-, C4_USB.2, C5.2, C5_USB.2, C6.2, C7.2, C9.2, C10.2, C10_SUPERCAP.1, C11.2, CHANGE_BUTTON.1, CHANGE_BUTTON.2, C_DELAY.2, D1.5 (VBUS), D3.1 (K), D6.1, D8.1, D9.1, D10.1, D11.1, D12.1, EPD_C1.2, EPD_C2.2, EPD_C5.2, EPD_C6.2, EPD_C7.2, EPD_C8.2, EPD_C9.2, EPD_C10.2, EPD_C11.2, EPD_C12.2, IC1.3 (GND), IC4.2 (VSS), J1.8, J1.17, J1.MP1, J1.MP2, J2.A1, J2.A12, J2.B1, J2.B12, J2.MP1, J2.MP2, J2.MP3, J2.MP4, J3.1, J4.G1 (GND_1), J4.G2 (GND_2), J4.G3 (GND_3), J4.G4 (GND_4), J4.P6 (VSS), MCP73831.2 (VSS), R1_PWRUSB.1, R2.1, R2-USB.2, R2-USB1.1, R2_BAT.1, R4.2, RESET_BUTTON.1, RESET_BUTTON.2, SENSOR2.1 (GND), SENSOR2.5 (SDO), SENSOR2.7 (GND), SJ1.1, TP4.TP, TP5.TP, U1.4 (GND), U1.9 (EXP), U2.1 (GND), U2.28 (GND), U2.29_1 (GND), U2.29_2 (GND), U2.29_3 (GND), U2.29_4 (GND), U2.29_5 (GND), U2.29_6 (GND), U2.29_7 (GND), U2.29_8 (GND), U2.29_9 (GND), U3.13 (GND), U4.1 (CTG), U4.4 (GND), U4.6 (QSTRT), U4.9 (EP)
GPIO8: R1.2, U2.10 (IO8)
I2C_PW: C1.1, C2.1, R1_PINH.2, R2-PINH.2, SENSOR2.2 (CSB), SENSOR2.6 (VDDIO), SENSOR2.8 (VDD), U2.17 (IO19)
INT_RTC: R1_PINH1.1, TP15.TP, U2.8 (IO0), U3.3 (SQW/!INT)
IO/BOOT: BOOT_BUTTON.3, BOOT_BUTTON.4, C6.1, R_BOOT.2, U2.15 (IO9)
IO/CHANGE: C10.1, CHANGE_BUTTON.3, CHANGE_BUTTON.4, R_CHANGE.2, U2.23 (IO15)
MISO: D12.2, J4.P7 (DAT0), R8.1, TP6.TP, U1.2 (DO(IO1)), U2.27 (IO2)
MOSI: D11.2, J1.14, J4.P3 (CMD), R7.1, TP7.TP, U1.5 (DI(IO0)), U2.7 (IO7)
unnamed: C9.1, J4.P4 (VDD)
unnamed: J2.A5, R2-USB1.2
unnamed: J2.B5, R2-USB.1
unnamed: C4.2, D5.2 (A)
unnamed: C4.1, D3.2 (A), D4.1 (K)
unnamed: C1_BAT1.1, D2.1 (CATHODE), IC4.1 (VIN), IC4.3 (CE), Q1.2 (S)
unnamed: MCP73831.1 (STAT), R1_BAT.1
unnamed: CHG_LED.C, R1_BAT.2
unnamed: C_DELAY.1, IC1.5 (CT)
unnamed: MCP73831.5 (PROG), R2_BAT.2
unnamed: EPD_C12.1, J1.24
unnamed: EPD_C2.1, J1.5
unnamed: EPD_C1.1, J1.4
unnamed: EPD_C10.1, J1.22
unnamed: D7.1 (CATHODE), R_CAPACITATOR.2
unnamed: EPD_C8.1, J1.20
unnamed: EPD_C7.1, J1.19
unnamed: EPD_C6.1, J1.18
PREVGH: D5.1 (K), EPD_C9.1, J1.21
PREVGL: D4.2 (A), EPD_C11.1, J1.23
RESE: J1.3, Q3.2 (S), R3.1
RESE': R2.2, R3.2, SJ1.2
RESET: C5.1, IC1.1 (VOUT), RESET_BUTTON.3, RESET_BUTTON.4, R_RESET.2, U2.3 (EN)
RTC_RST: U2.16 (IO18), U3.4 (!RST)
RX: TP2.TP, U2.24 (RXD0/GPIO17)
SCK: D10.2, J1.13, J4.P5 (CLK), R6.1, TP8.TP, U1.6 (CLK), U2.6 (IO6)
SCL: J3.4, R2-PINH.1, SENSOR2.4 (SCK), U2.20 (IO22), U3.16 (SCL), U4.7 (SCL)
SDA: J3.3, R1_PINH.1, SENSOR2.3 (SDI), U2.19 (IO21), U3.15 (SDA), U4.8 (SDA)
SRC: L1.1, Q3.3 (D)
SS_SD: D8.2, J4.P2 (CD/DAT3), R10.1, U2.4 (IO4)
TX: TP1.TP, U2.25 (TXD0/GPIO16)
USB_D+: D1.4 (I/O2_2), U2.14 (IO13)
USB_D-: D1.6 (I/O1_2), U2.13 (IO12)
VBAT: C2_BAT.1, MCP73831.3 (VBAT), Q1.3 (D), TP3.TP, U4.2 (CELL), U4.3 (VDD)
VBUS: C1_BAT.1, C4_USB.1, C5_USB.1, CHG_LED.A, D1.2 (GND), D2.2 (ANODE), MCP73831.4 (VIN), PFMF.050.1.2, Q1.1 (G), R1_PWRUSB.2, TP14.TP
VRTC: C10_SUPERCAP.2, C11.1, R_CAPACITATOR.1, U3.14 (VBAT)
VUSB: J2.A4, J2.A9, J2.B4, J2.B9, PFMF.050.1.1

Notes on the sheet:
USB C connector & ESD protection
LDO Voltage Regulator
SD Card
Display Type Selector
E-Paper Drive Circuit
Li-Po Battery Charging Controller
ESP32 C6
E-Paper Display Header
EPD Power
Environmental Sensor BME688
Voltage Supervisor + Reset & Boot / IO Button
Battery ChargeLevel
RTC Module DS3231SN
Test Pads
Qwiic / Stemma QT
SPI ESD Protection Lines
External NORFlash64MB

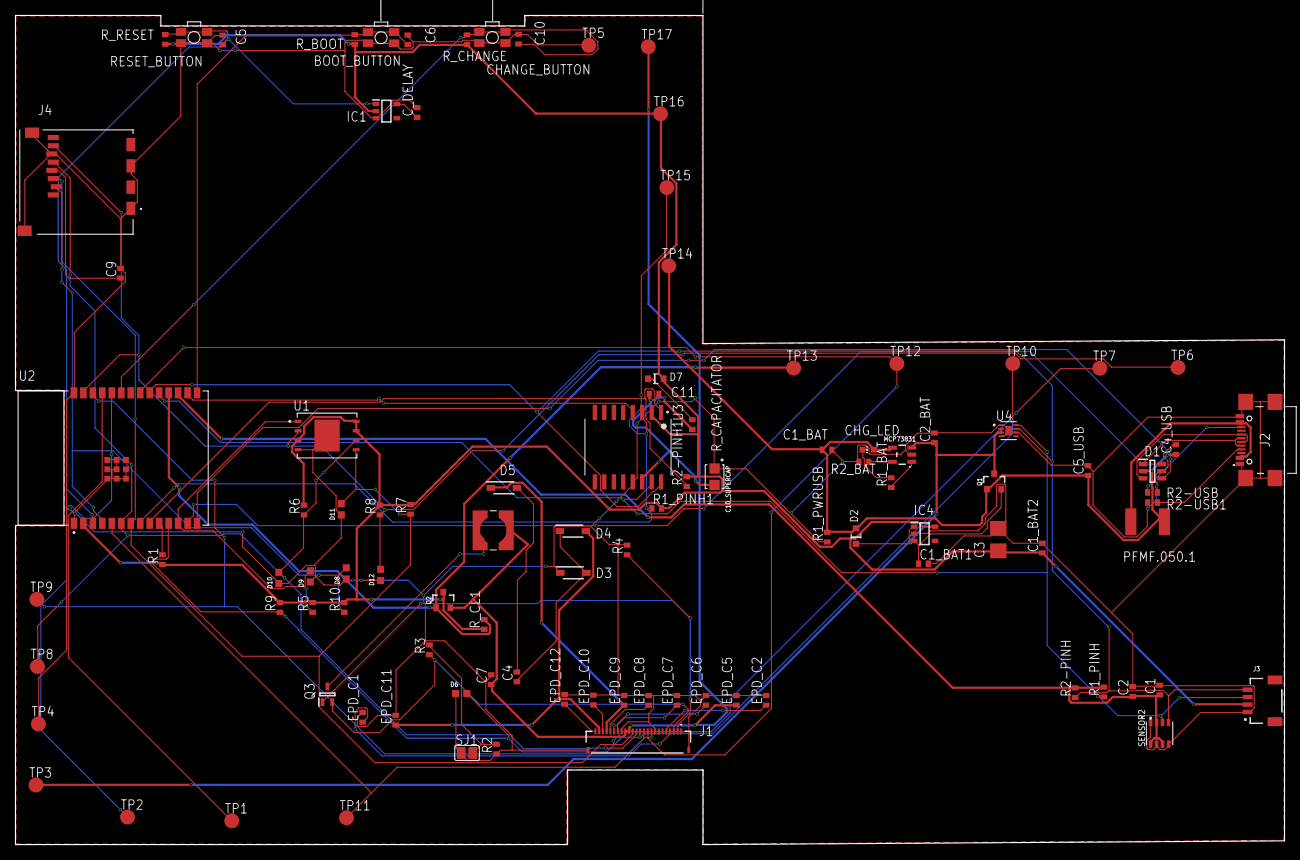
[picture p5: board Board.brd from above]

Board: 2 copper layers, 170.2 x 111.2 mm, 103 parts (0 on the bottom side), 57 nets.

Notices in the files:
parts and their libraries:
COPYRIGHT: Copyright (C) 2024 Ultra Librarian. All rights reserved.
